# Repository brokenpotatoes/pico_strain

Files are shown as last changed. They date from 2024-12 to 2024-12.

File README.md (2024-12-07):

# Raspberry Pi Pico Strain Gauge Data Acquisition System

This project is an 8-channel strain gauge data acquisition system built around the Raspberry Pi Pico. It can also be used for any precision resistance measurement using a Wheatstone bridge. It features a Texas Instruments 8-channel, 24-bit ADC with adjustable gain (1 to 128) and a sampling rate of up to 32 kSPS. The system provides up to 9V, 250mA shared excitation voltage for the channels, which can be adjusted by soldering resistors on the PCB. Future revisions plan to support 10V excitation, which will require a power supply of more than 5.5V.

The PCB for this project was designed using **Altium Designer**.

---
## Background Story

This system was designed for **CLES-FACIL**, the rocket club at **INSA Lyon**, to measure loads on an experimental rocket during flight. The goal is to integrate this data acquisition system into a rocket that has a diameter of only **100mm**, meaning we need to make the system as small and efficient as possible. By using strain gauges, the system will monitor forces on the rocket in real-time, providing critical data that can be used to optimize the rocket's design and performance for future flights.

---

## Features

- **8 Channels**: Supports up to 8 sensors.  
- **High Precision**: 24-bit ADC with adjustable gain (1 to 128).  
- **High Sampling Rate**: Up to 32 kSPS.  
- **Adjustable Excitation Voltage**: Up to 9V (250mA shared), adjustable using resistors soldered on the PCB.  
- **Trusted Components**: This project uses only components from trusted and established manufacturers.  

---

## PCB Design
 
- Currently, the PCB size is **65mm x 45mm**, and the plan is to make it even smaller in future revisions.  
- [View the Schematic Here](hardware/revA/docs/REV_A_SCH.pdf) (PDF).  
- PCB pictures:  
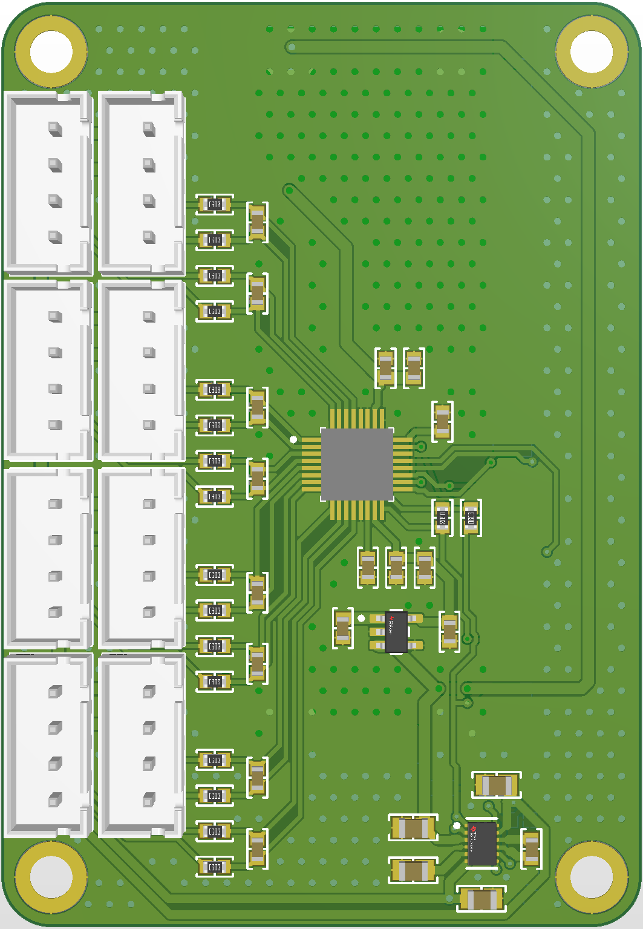
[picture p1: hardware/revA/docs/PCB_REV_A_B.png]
Top View Placeholder
    
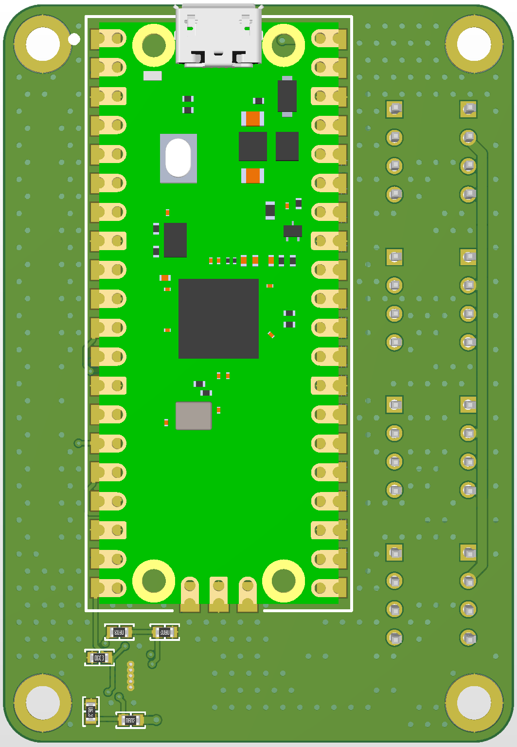
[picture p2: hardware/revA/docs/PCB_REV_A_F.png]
Bottom View Placeholder
    

---

## Future Revisions

- **10V Excitation**: Planned support using a higher voltage non-USB power supply.  
  - **Note**: 10V excitation will require a power supply of more than 5.5V.  
- **RS-485 Networking**: Add support for 10 Mbps communication via RS-485, allowing multiple boards to be connected together. This will require overclocking the Raspberry Pi Pico to 160 MHz.  
- **USB Type-C Connectors**: Replace JST-XH connectors with USB Type-C for their smaller size and affordability (USB 2.0 cables available for as low as $0.30). USB Type-C will also support RS-485 communication.  
- **Power Supply**: Future revisions will likely be powered by 12V or 24V sources, as each board requires up to 10W for the excitation voltage.  
- **Excitation Voltage Control**: For future revisions, I plan to make the excitation voltage adjustable using a DAC for more precise and programmable control.  

---

## TODO List

- [x] Get basic functionality working  
- [ ] Make a CLI-style basic interface  
- [ ] Implement a protocol for RS-485  
- [ ] Measure power supply noise (currently unable due to broken oscilloscope probe)  
- [ ] Make a 2nd revision PCB
- [ ] Delta encoding compression for sending data  

---

## License

Licensed under the MIT License.  

---

## Contact

For questions, contact **Bogdan Seczkowski** or open an issue.

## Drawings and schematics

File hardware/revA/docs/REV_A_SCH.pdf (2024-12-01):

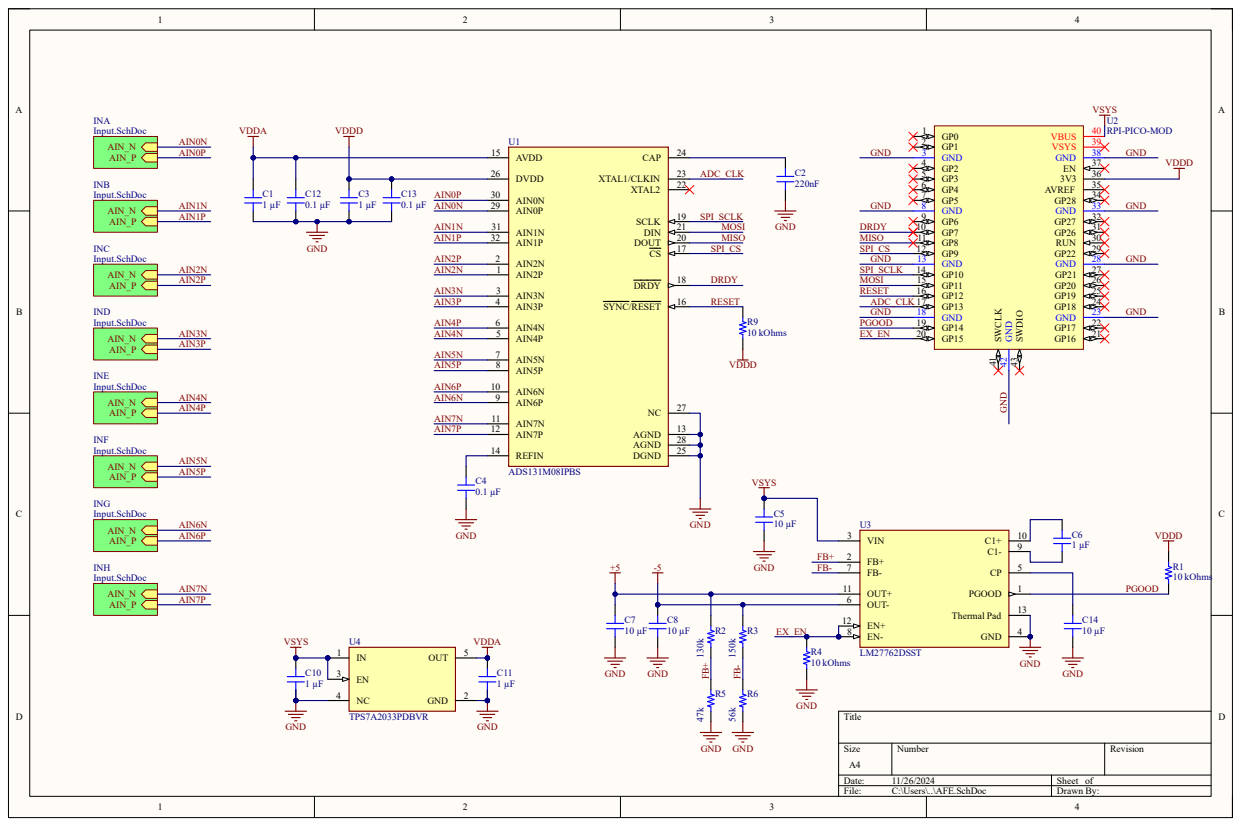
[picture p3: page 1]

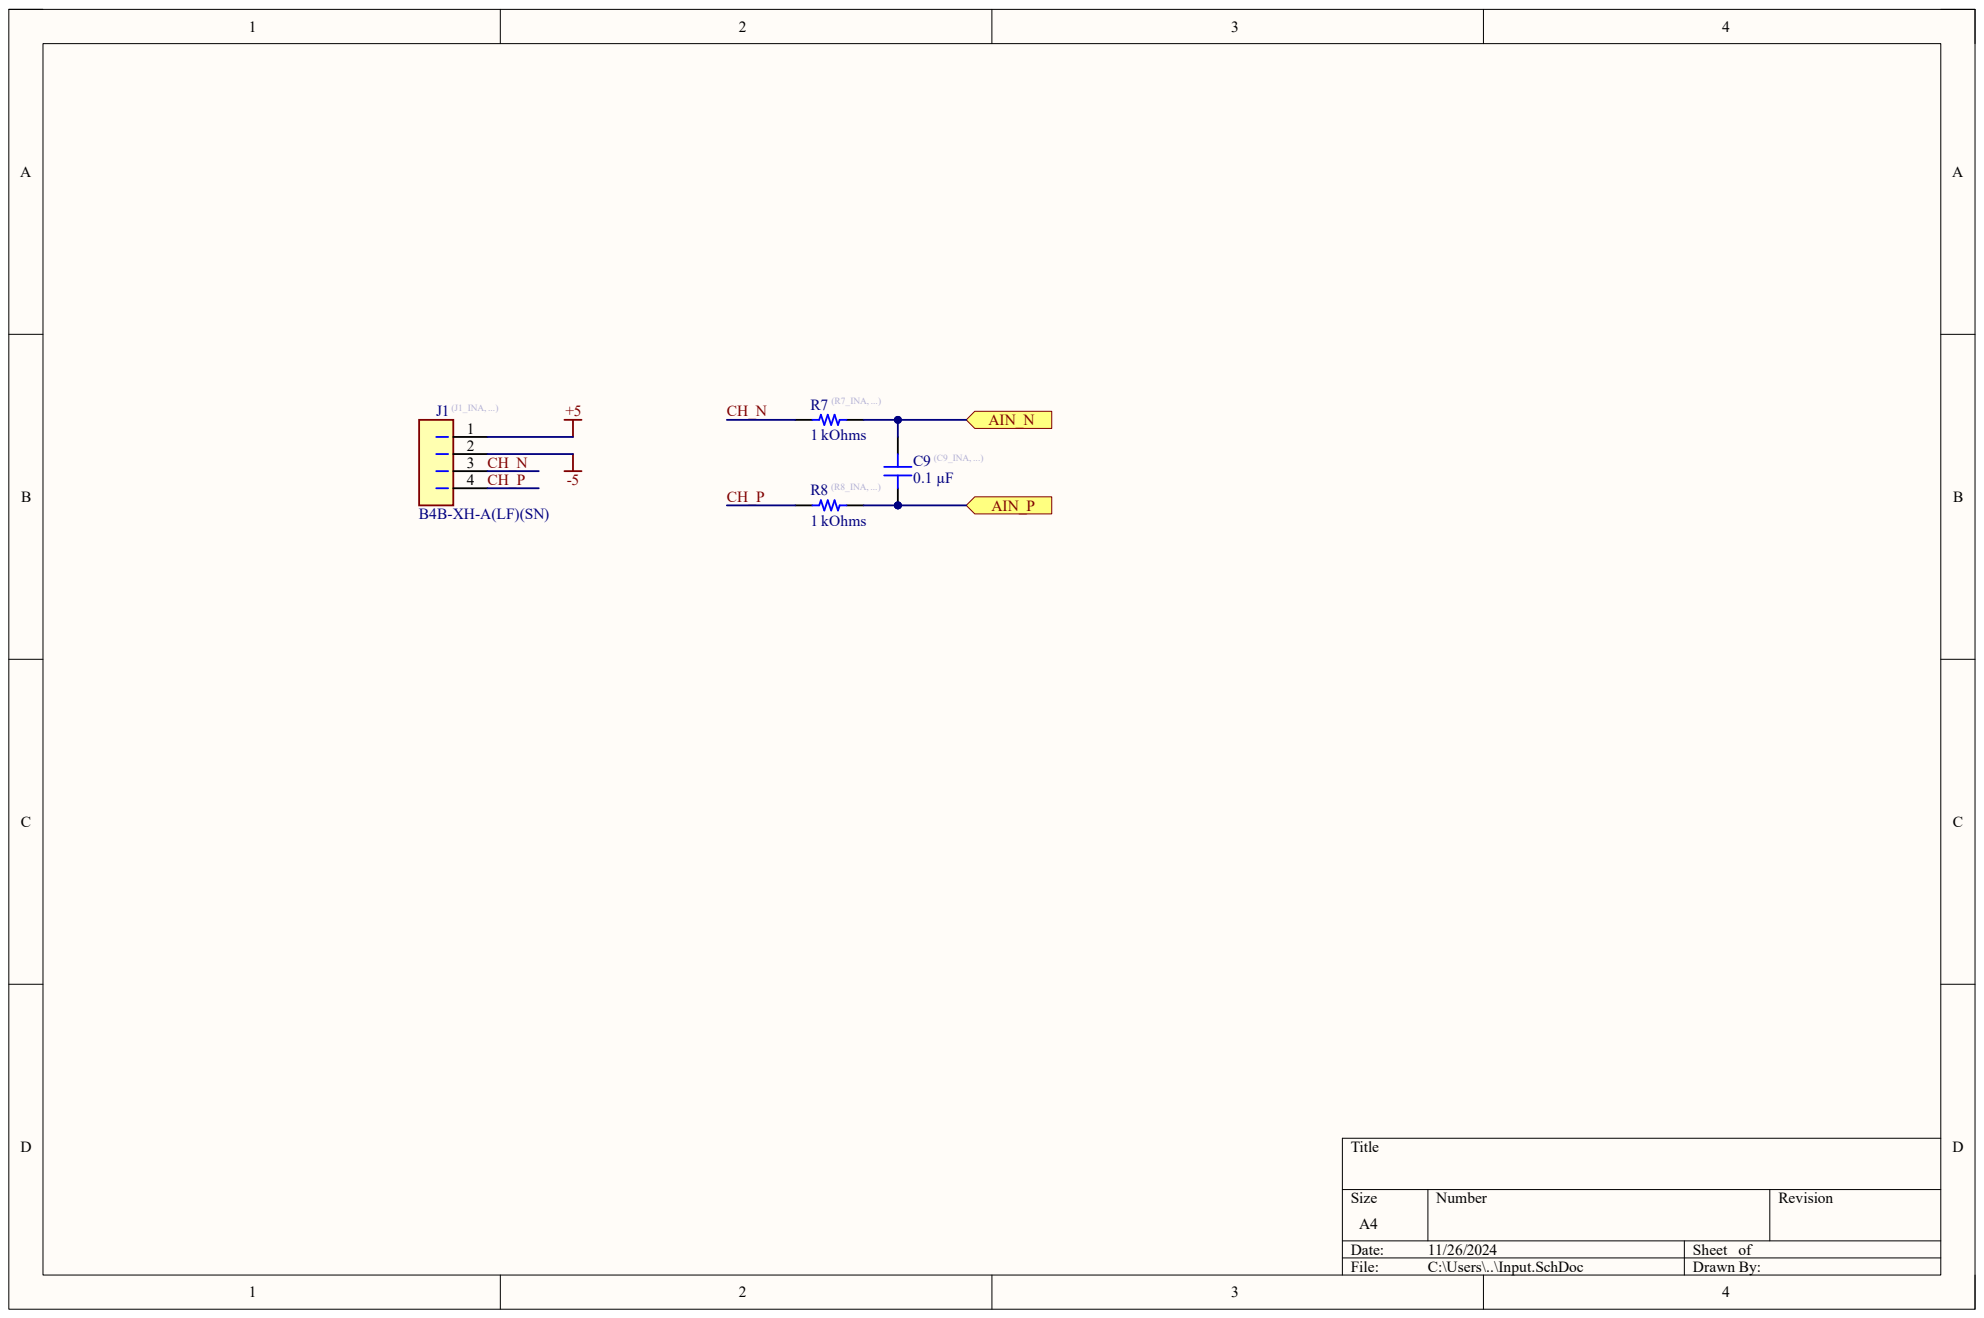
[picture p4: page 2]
Title; Size; Number; Revision; Date:; Sheet of; File:; C:\Users\..\Input.SchDoc; Drawn By:; AIN_N; AIN_P; J1⁽J1_INA, ...); 1 kOhms; R7 ⁽R7_INA, ...); R8 ⁽R8_INA, ...); C9 ⁽C9_INA, ...)

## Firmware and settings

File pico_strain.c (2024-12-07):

/**
 * Copyright (c) 2020 Raspberry Pi (Trading) Ltd.
 *
 * SPDX-License-Identifier: BSD-3-Clause
 */

#include "pico/stdlib.h"
#include <stdio.h>
#include "ads131m0x.h"
#include "hal.h"
#ifndef LED_DELAY_MS
#define LED_DELAY_MS 250
#endif
// Initialize the GPIO for the LED
void pico_led_init(void) {
gpio_init(25);
gpio_init(15);
gpio_set_dir(25, GPIO_OUT);
gpio_set_dir(15, GPIO_OUT);
}

// Turn the LED on or off
void pico_set_led(bool led_on) {
    gpio_put(25, led_on);
}
adc_channel_data data;
int main() {
    stdio_init_all();
    pico_led_init();
    adcStartup();
    while (true) {
        if(flag_nDRDY_INTERRUPT){
            flag_nDRDY_INTERRUPT=false;
            readData(&data);
            printf("%d,%d,%d,%d,%d,%d,%d,%d\n",data.channel0,data.channel1,data.channel2,data.channel3,
                data.channel4,data.channel5,data.channel6,data.channel7);
        }
    }
}

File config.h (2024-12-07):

//Pin defs
//Excitation control
#define EX_EN_PIN 15;
#define PGOOD 16;
//ADC Pins
#define SPI_FREQ            25e6 // 25mhz -> max SPI freq of the ADC
#define nDRDY_PIN           7
#define nCS_PIN             9
#define nSYNC_nRESET_PIN    12
#define CLK_PIN             21 //Only for RP2040 CLK not availible on pin 13
#define MISO_PIN            8
#define MOSI_PIN            11
#define SCK_PIN             10

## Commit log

2024-12-01 Add Hardware docs
    [AFE.SchDoc, Input.SchDoc, PCB.PcbDoc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]
2024-12-07 Semi working early prototype
    Now after initializing the board streams ADC data over USB
